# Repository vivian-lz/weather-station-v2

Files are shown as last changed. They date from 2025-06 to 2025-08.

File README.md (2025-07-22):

# weather-station-v2
To expand on my first weather station product, I am creating a more advanced version that uses PCB design, I2C communication, and STM32/ESP32 microcontrollers.

The first iteration utilizes the ESP32 module as the base microcontroller and a BME280 module as the main chip that senses the temperature, humidity, pressue, and approximate altitude. This PCB has been created but has not yet been assembled or manufactured.

Since circuits that utilize modules often are constrained by size and control over communication, I also wanted to dive deeper into circuit design by creating a device that utilizes the raw IC chips rather than just modules. I am currently in the process of creating the schematic for this device, which utilizes an ESP32 C6FH4 and the raw BME280 IC. In addition, it utilizes USB-C connection with a USB-to-Serial chip for communication as well as a MIC5365 LDO to drop the voltage that enters the USB from 5 to 3.3 V before it enters the ESP32 chip to avoid frying the chip/board. This device also includes a 40 kHz crystal to generate a constant clock signal for the device and a reset button to manually reset the ESP32 if needed. Finally, the device still contains the traditional RGB and the LCD of the original design to display information in different ways.

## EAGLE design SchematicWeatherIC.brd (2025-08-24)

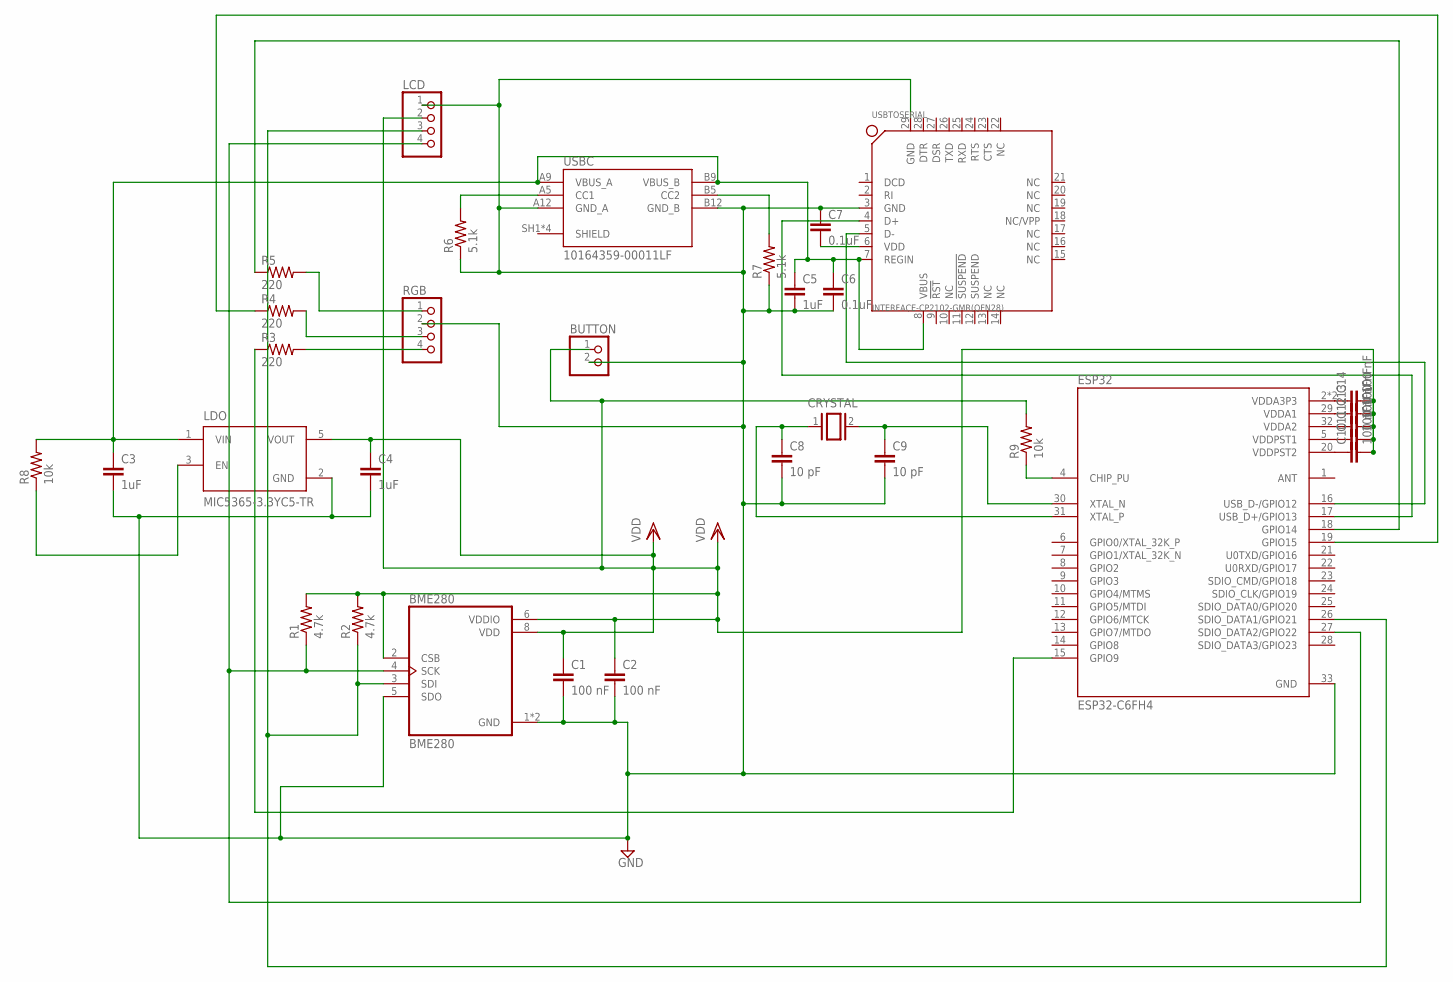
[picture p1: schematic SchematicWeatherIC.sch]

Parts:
BME280: BME280; PSON65P250X250X100-8N
BUTTON: PINHD-1X2; 1X02
C1, C2, C10, C11, C12, C13, C14: 100 nF; C5B3
C3, C4, C5: 1uF; C5B2.5
C6, C7: 0.1uF; C5B2.5
C8, C9: 10 pF; C5B3
CRYSTAL: XTAL/S; QS
ESP32: ESP32-C6FH4; QFN50P500X500X90-33N
LCD: PINHD-1X4; 1X04
LDO: MIC5365-3.3YC5-TR; SOT65P210X110-5N
R1, R2: 4.7k; VMTA55
R3, R4, R5: 220; VMTA55
R6, R7: 5.1k; VMTA55
R8, R9: 10k; VMTA55
RGB: PINHD-1X4; 1X04
USBC: 10164359-00011LF; AMPHENOL_10164359-00011LF
USBTOSERIAL: INTERFACE-CP2102-GMR(QFN28); QFN28G_0.5-5X5MM

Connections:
D_N: ESP32.16 (USB_D-/GPIO12), USBTOSERIAL.5 (D-)
D_P: ESP32.17 (USB_D+/GPIO13), USBTOSERIAL.4 (D+)
GND: BME280.1 (GND), BME280.5 (SDO), BME280.7 (GND), BUTTON.2, C1.2, C2.2, C3.2, C4.2, C5.2, C6.2, C7.1, C8.2, C9.2, ESP32.33 (GND), LCD.1, LDO.2 (GND), R6.1, R7.1, RGB.2, USBC.A12 (GND_A), USBC.B12 (GND_B), USBTOSERIAL.3 (GND), USBTOSERIAL.29 (GND)
unnamed: ESP32.15 (GPIO9), R3.1
unnamed: C3.1, C5.1, C6.1, LDO.1 (VIN), R8.2, USBC.A9 (VBUS_A), USBC.B9 (VBUS_B), USBTOSERIAL.7 (REGIN), USBTOSERIAL.8 (VBUS)
unnamed: ESP32.4 (CHIP_PU), R9.1
unnamed: ESP32.18 (GPIO14), R5.1
unnamed: C7.2, USBTOSERIAL.6 (VDD)
unnamed: LDO.3 (EN), R8.1
unnamed: ESP32.19 (GPIO15), R4.1
unnamed: R3.2, RGB.4
unnamed: R4.2, RGB.3
unnamed: R5.2, RGB.1
unnamed: C8.1, CRYSTAL.1, ESP32.31 (XTAL_P)
unnamed: R6.2, USBC.A5 (CC1)
unnamed: R7.2, USBC.B5 (CC2)
unnamed: C10.1, ESP32.20 (VDDPST2)
unnamed: C9.1, CRYSTAL.2, ESP32.30 (XTAL_N)
unnamed: C11.1, ESP32.5 (VDDPST1)
unnamed: C12.1, ESP32.32 (VDDA2)
unnamed: C13.1, ESP32.29 (VDDA1)
unnamed: C14.1, ESP32.2 (VDDA3P3), ESP32.3 (VDDA3P3)
SCL: BME280.4 (SCK), ESP32.27 (SDIO_DATA2/GPIO22), LCD.4, R1.1
SDA: BME280.3 (SDI), ESP32.26 (SDIO_DATA1/GPIO21), LCD.3, R2.1
VDD: BME280.2 (CSB), BME280.6 (VDDIO), BME280.8 (VDD), BUTTON.1, C1.1, C2.1, C4.1, C10.2, C11.2, C12.2, C13.2, C14.2, LCD.2, LDO.5 (VOUT), R1.2, R2.2, R9.2

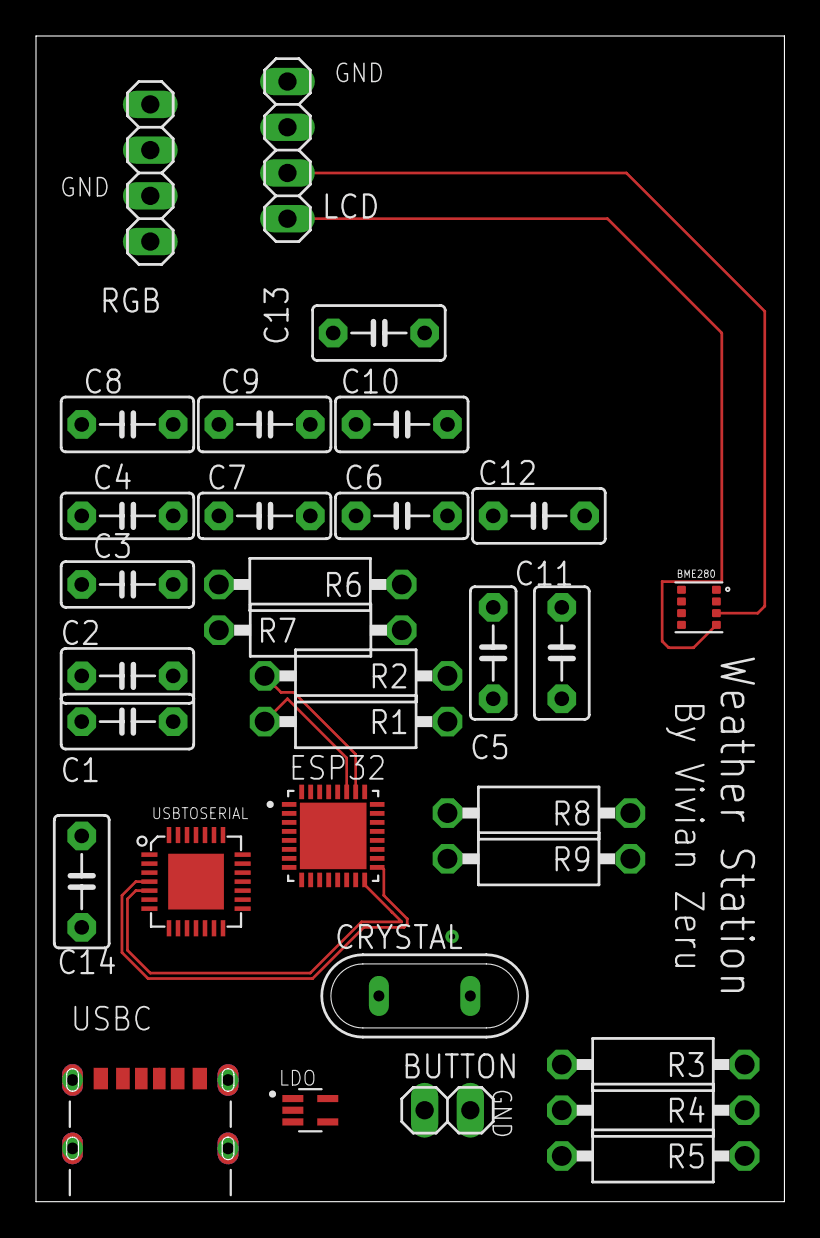
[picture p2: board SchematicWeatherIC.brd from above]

Board: 2 copper layers, 41.6 x 64.8 mm, 32 parts (0 on the bottom side), 25 nets.

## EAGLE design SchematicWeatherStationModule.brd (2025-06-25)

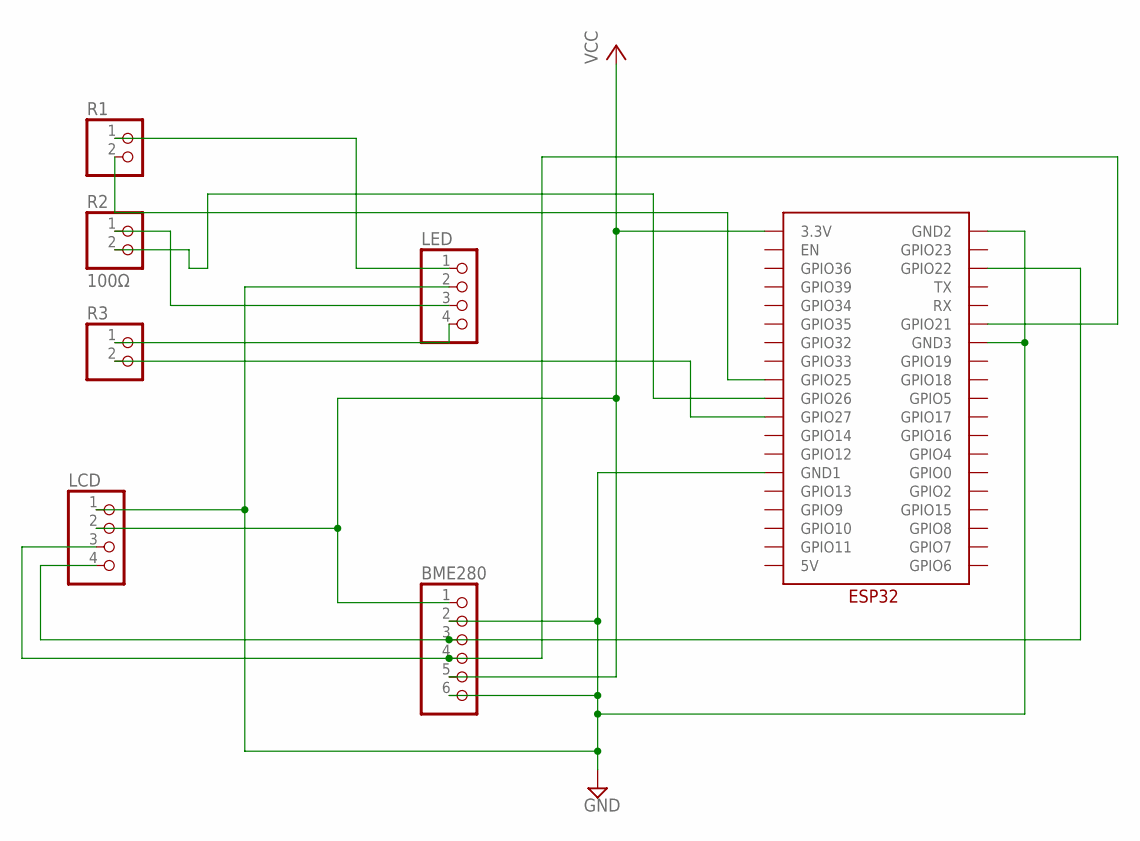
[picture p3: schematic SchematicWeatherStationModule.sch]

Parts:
BME280: PINHD-1X6/90; 1X06/90
LCD: PINHD-1X4/90; 1X04/90
LED: PINHD-1X4; 1X04
R1, R3: PINHD-1X2; 1X02
R2: 100Ω; 1X02
U$1: ESP32

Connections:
GND: BME280.2, BME280.6, LCD.1, LED.2, U$1.GND1, U$1.GND2, U$1.GND3
unnamed: LED.1, R1.1
unnamed: LED.3, R2.1
unnamed: LED.4, R3.1
unnamed: R3.2, U$1.GPIO27
unnamed: R1.2, U$1.GPIO25
unnamed: R2.2, U$1.GPIO26
SCL: BME280.3, LCD.4, U$1.GPIO22
SDA: BME280.4, LCD.3, U$1.GPIO21
VCC: BME280.1, BME280.5, LCD.2, U$1.3.3V

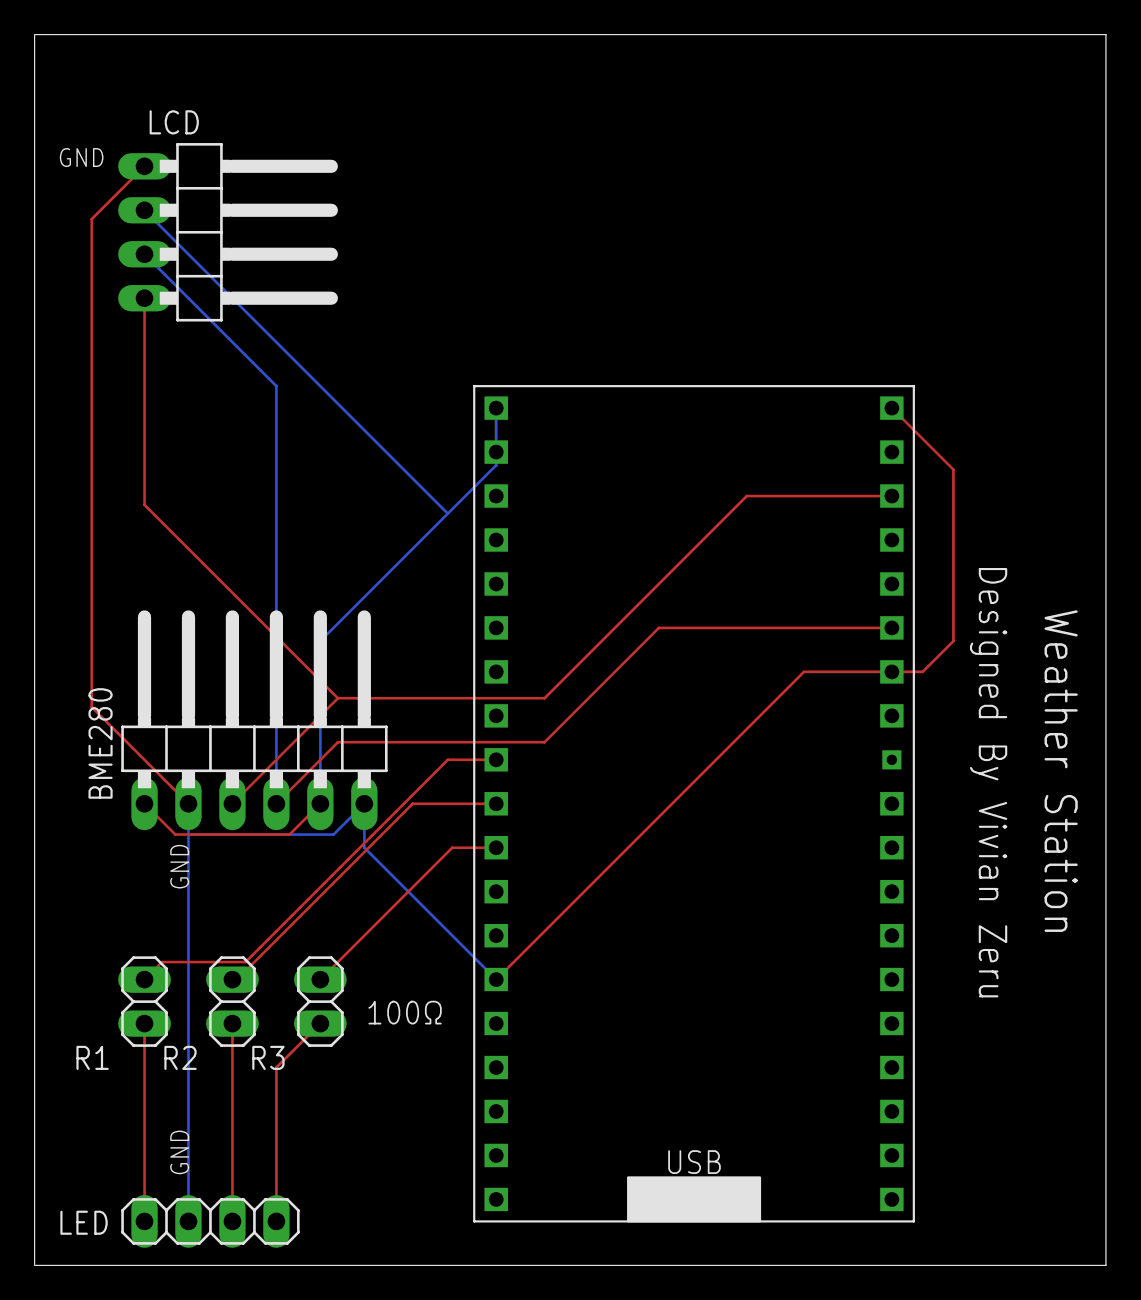
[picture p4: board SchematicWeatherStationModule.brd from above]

Board: 2 copper layers, 61.9 x 71.1 mm, 7 parts (0 on the bottom side), 10 nets.

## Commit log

2025-06-25 Schematic and Layout (using Modules)
    This PCB schematic and layout was designed in Eagle and uses both the ESP32 and BME280 module in its design.
    [SchematicWeatherStationModule.brd, SchematicWeatherStationModule.sch]
2025-07-22 adding all components and starting connections
    [SchematicWeatherIC.sch]
2025-07-24 finish mostly all connections except to esp32 ic
    [SchematicWeatherIC.sch]
2025-07-24 add crystal connection
    [SchematicWeatherIC.sch]
2025-07-25 add lcd and some vdd connections
    [SchematicWeatherIC.sch]
2025-07-25 all main connections on schematic complete
    [SchematicWeatherIC.sch]
2025-07-25 connect vdd esp32
    [SchematicWeatherIC.sch]
2025-07-25 some extra touches
    [SchematicWeatherIC.sch]
2025-07-25 created board and moved in components to layout
    [BoardWeatherIC.brd]
2025-07-26 add decoupling capacitors to power
    [SchematicWeatherIC.sch]
2025-07-26 add updates due to schematic update
2025-07-30 use smaller resistors and autoroute
    [SchematicWeatherIC.sch]
2025-07-30 add smaller resistors and autoroute
    [SchematicWeatherIC.brd]
2025-07-30 update name to label old board
    [WeatherICV1.brd]
2025-08-04 some wiring and routing updates in progress
    [BoardWeatherIC.brd, SchematicWeatherIC.sch]
2025-08-04 this is where the routing updates are in progress
    [SchematicWeatherIC.brd]
2025-08-10 routed differential pair and i2c
    [SchematicWeatherIC.brd, SchematicWeatherIC.sch]
